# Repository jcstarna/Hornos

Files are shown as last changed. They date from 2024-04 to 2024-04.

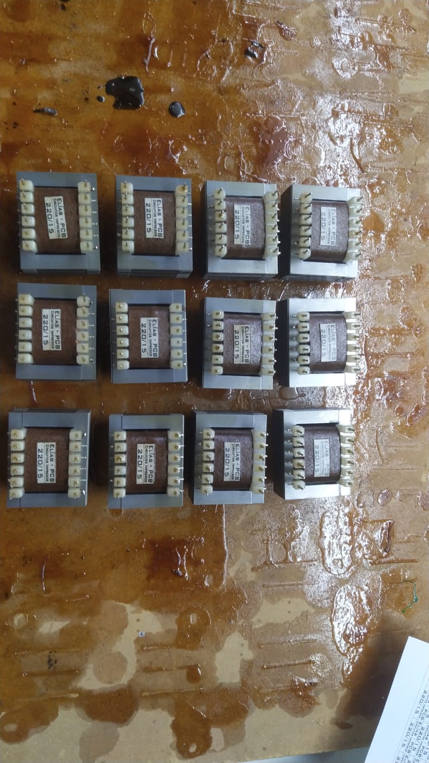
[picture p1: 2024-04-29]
docs/fotos/WhatsApp Image 2022-01-06 at 21.31.58.jpeg

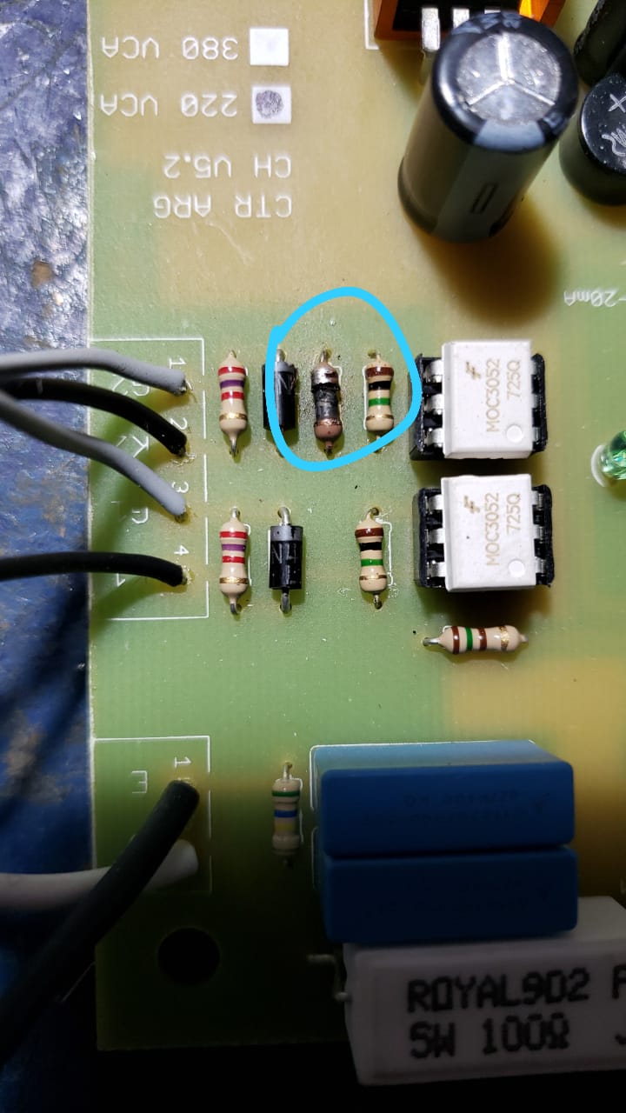
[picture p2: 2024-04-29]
docs/fotos/IMG-20210729-WA0018.jpg

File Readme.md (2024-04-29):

# Controlador de Hornos

Controlador de Hornos

## Requisitos
+ Puglin MPLAB 'CCS C Compiler' instalado. (Tools -> Plugins) 
+ Compilador CCS version 5.093 instalado en el sistema

## Verificar
+ Verificar que las rutas sean correctas en:  Project  -> Properties -> Conf: [nombre] -> CCS C Compiler -> Compiler Options -> Include Directoies

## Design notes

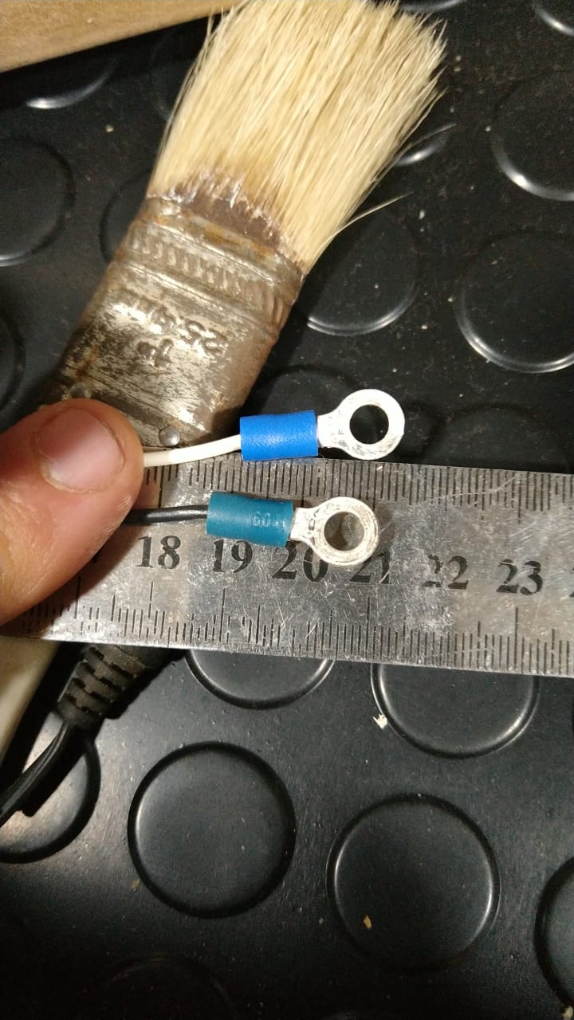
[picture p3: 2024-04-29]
docs/fotos/IMG-20210519-WA0052.jpg

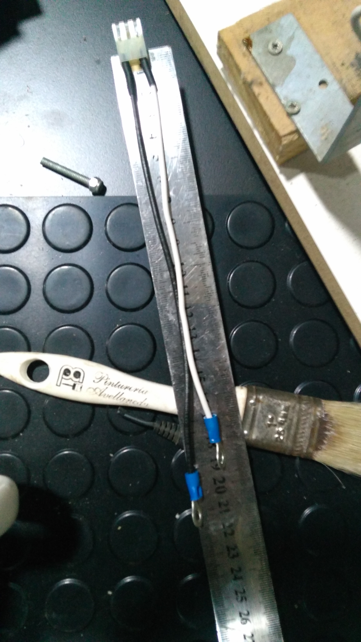
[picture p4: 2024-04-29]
docs/fotos/IMG-20210519-WA0053.jpeg

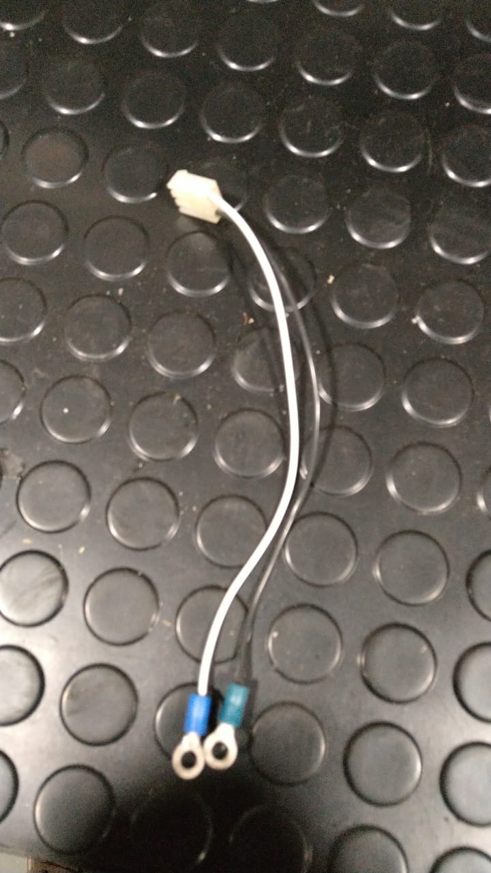
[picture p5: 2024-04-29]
docs/fotos/IMG-20210519-WA0051.jpg

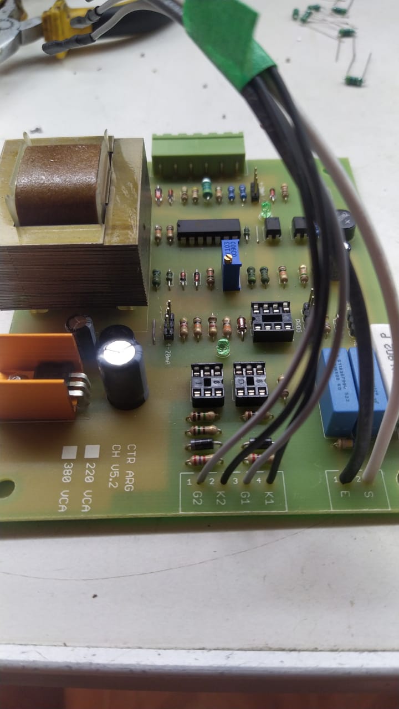
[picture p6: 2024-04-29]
docs/fotos/IMG-20210226-WA0002.jpg

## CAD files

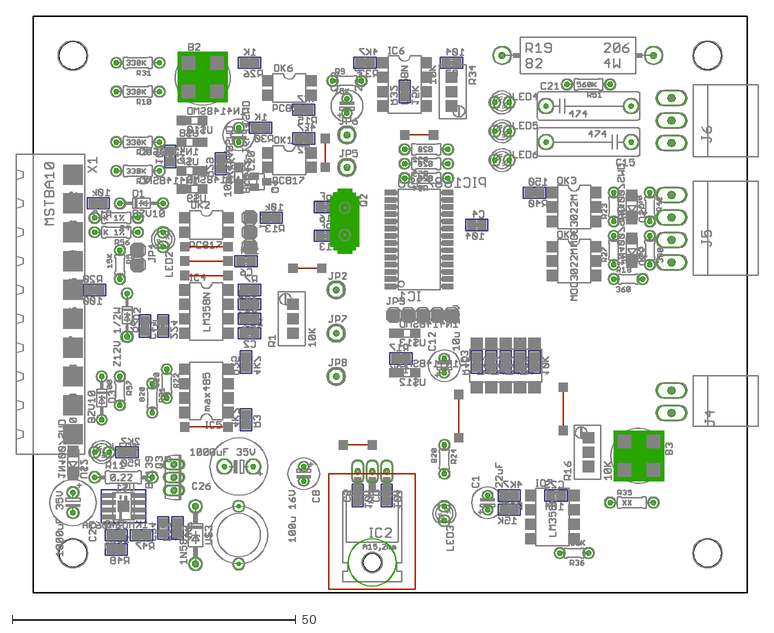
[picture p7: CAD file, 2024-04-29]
docs/ctrol_hornos_micro V32.dxf
130.7 x 101.6

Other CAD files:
docs/conexiones.dwg

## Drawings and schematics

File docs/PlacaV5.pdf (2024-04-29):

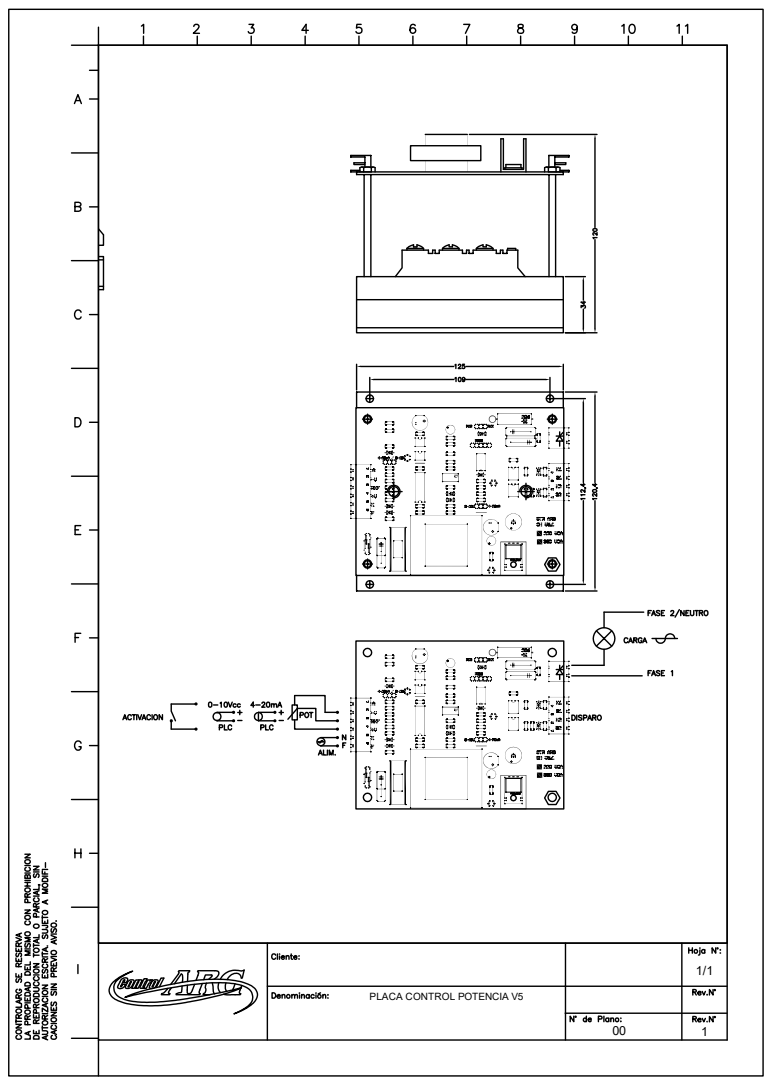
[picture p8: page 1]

PLACA CONTROL POTENCIA V5

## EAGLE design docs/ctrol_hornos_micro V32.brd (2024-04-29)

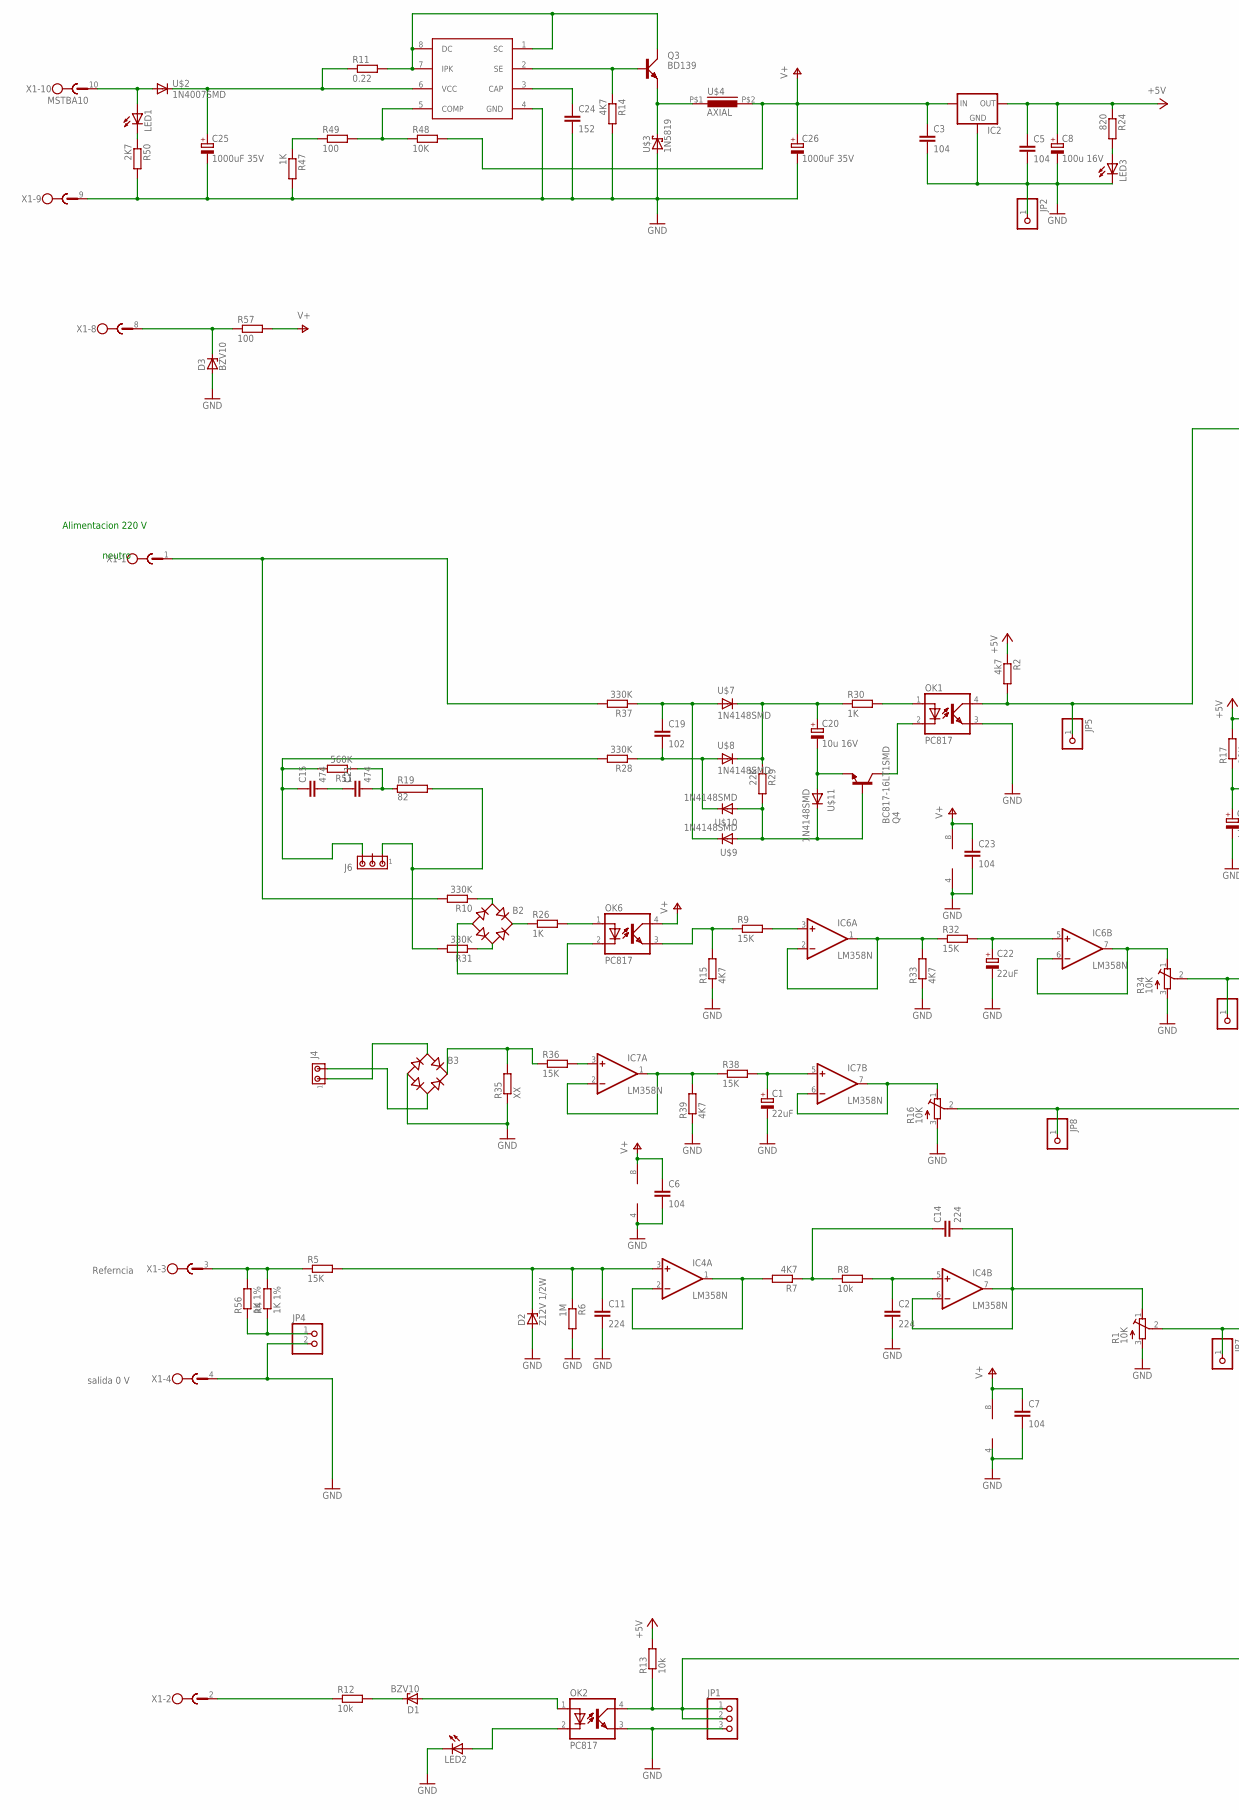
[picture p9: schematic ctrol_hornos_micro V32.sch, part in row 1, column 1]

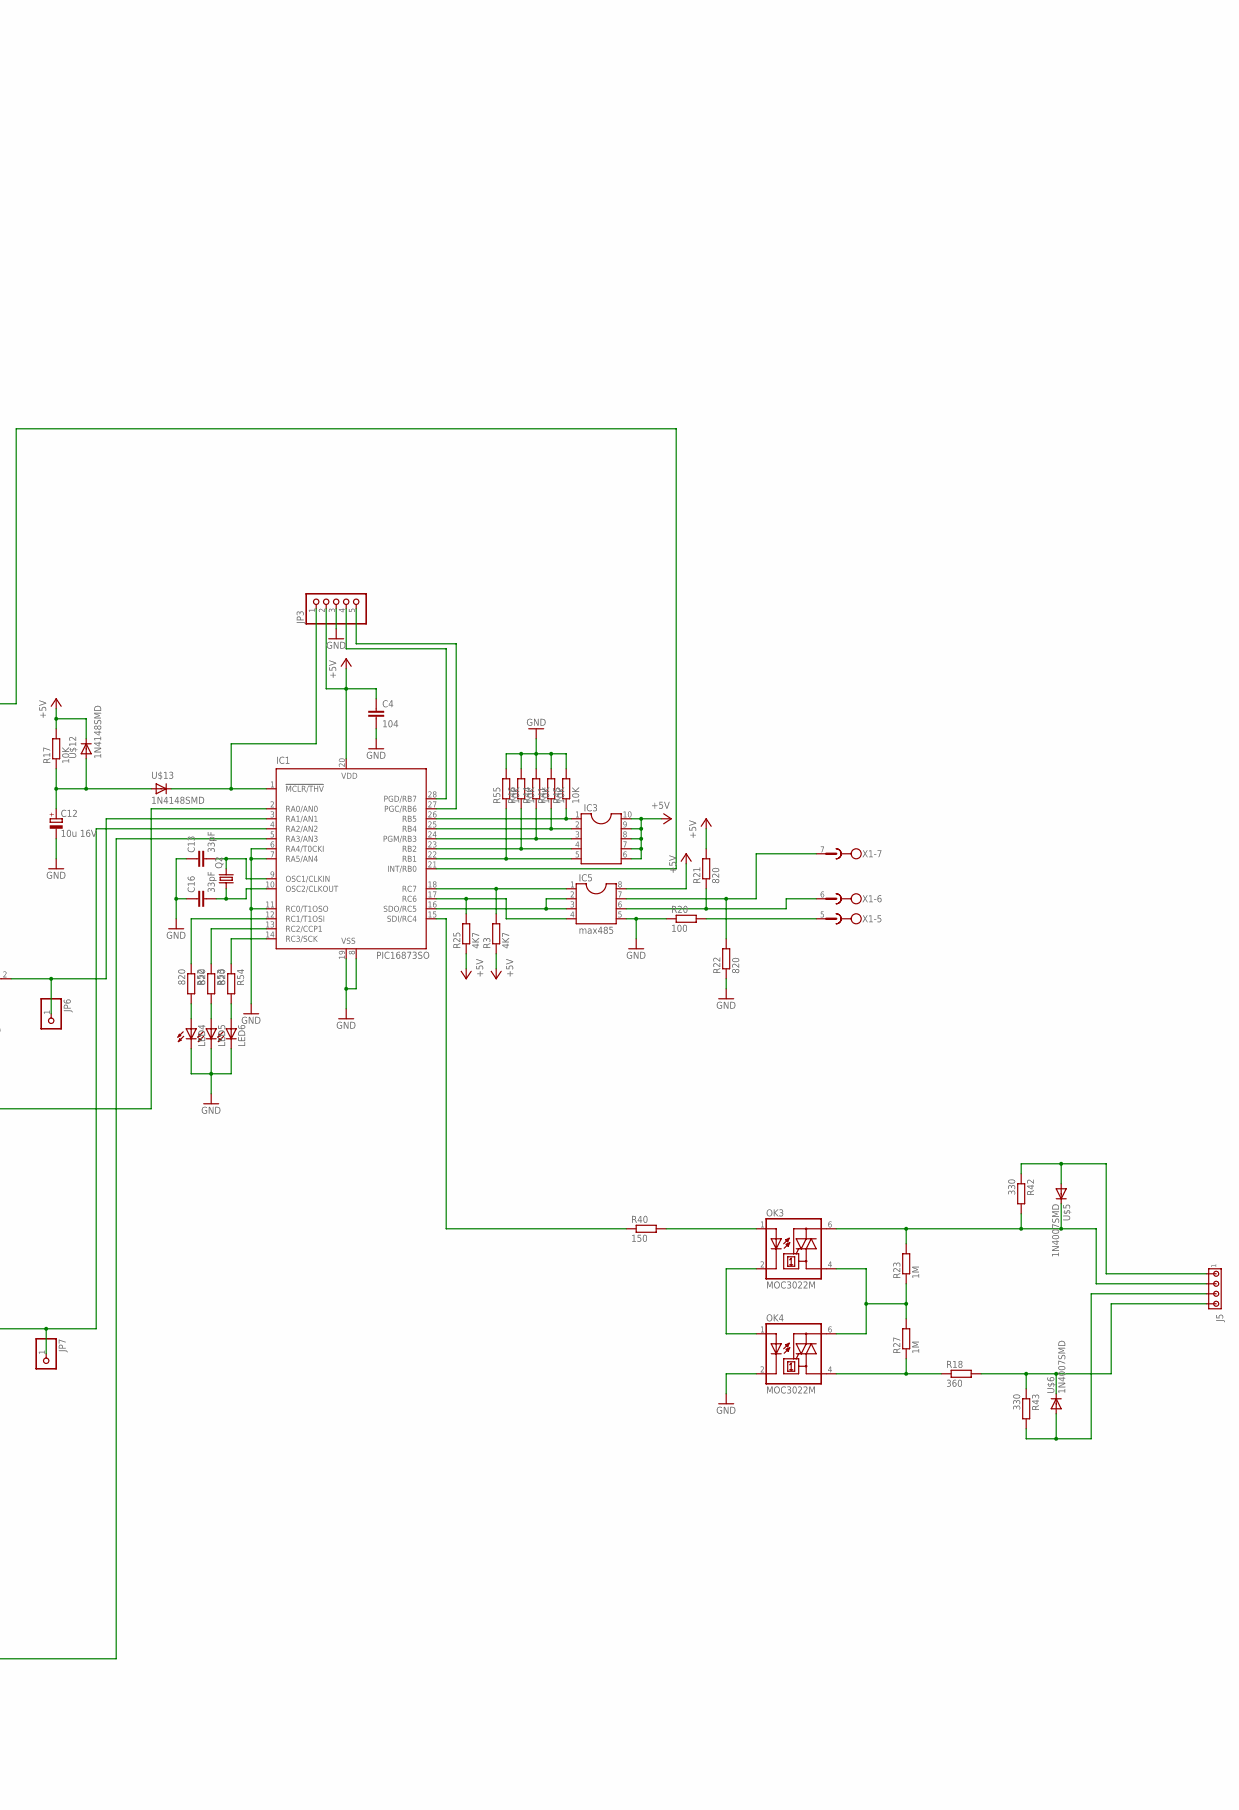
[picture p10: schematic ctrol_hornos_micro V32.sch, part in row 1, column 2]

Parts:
B2, B3: RB1A
C1, C22: 22uF; E2,5-6
C2, C11, C14: 224; C0805
C3, C4, C5, C6, C7, C23: 104; C0805
C8: 100u 16V; E2,5-6
C12, C20: 10u 16V; E2,5-6
C13, C16: 33pF; C0805
C15, C21: 474; C150-054X183
C19: 102; C0805
C24: 152; C0805
C25: 1000uF 35V; E3,5-8
C26: 1000uF 35V; E5-10,5
D1, D3: BZV10; DO34Z7
D2: Z12V 1/2W; DO34Z7
IC1: PIC16873SO; SO28W
IC2: 78XXL
IC3: DIL10
IC4, IC6, IC7: LM358N; DIL08
IC5: max485; DIL08
J4: MTA02-156; 1X2MTA
J5: MTA04-156; 1X4MTA
J6: MTA03-156; 1X3MTA
JP1: PINHD-1X3; 1X03
JP2, JP5, JP6, JP7, JP8: PINHD-1X1; 1X01
JP3: PINHD-1X5; 1X05
JP4: PINHD-1X2; 1X02
LED1, LED2, LED3, LED4, LED5, LED6: LED3MM
OK1, OK2, OK6: PC817; DIL04
OK3, OK4: MOC3022M; DIL06
Q2: CRYTALHC49S; HC49/S
Q3: BD139; TO126AV
Q4: BC817-16LT1SMD; SOT23-BEC
R1, R16, R34: 10K; RTRIMT93YA
R2: 4k7; M0805
R3, R7, R14, R15, R25, R33, R39: 4K7; M0805
R4, R56: 1K 1%; 0204/7
R5, R9, R36: 15K; 0204/5
R6: 1M; M0805
R8, R12, R13: 10k; M0805
R10, R28, R31, R37: 330K; 0204/7
R11: 0.22; 0207/10
R17, R41, R44, R45, R46, R48, R55: 10K; M0805
R18: 360; 0204/5
R19: 82; KH206-8
R20, R49: 100; M0805
R21, R22, R24: 820; 0204/5
R23, R27: 1M; 0204/5
R26, R30, R47: 1K; M0805
R29: 22K; M0805
R32, R38: 15K; M0805
R35: XX; 0204/7
R40: 150; M0805
R42, R43: 330; 0204/5
R50: 2K7; M0805
R51: 560K; 0204/7
R52, R53, R54: 820; 0204/7
R57: 100; 0204/5
U$1: MC34063A; SO-08
U$2, U$5, U$6: 1N4007SMD; DO214AC
U$3: 1N5819; DO41Z10
U$4: AXIAL; AXIAL1
U$7, U$8, U$9, U$10, U$11, U$12, U$13: 1N4148SMD; SOD123
X1: MSTBA10

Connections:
+5V: C4.1, C5.1, C8.+, IC1.20 (VDD), IC2.OUT, IC3.6, IC3.7, IC3.8, IC3.9, IC3.10, IC5.8, JP3.2, R2.1, R3.1, R13.2, R17.2, R21.2, R24.1, R25.1, U$12.C
GND: B3.-, C1.-, C2.2, C3.2, C4.2, C5.2, C6.2, C7.2, C8.-, C11.2, C12.-, C13.1, C16.1, C22.-, C23.2, C24.2, C25.-, C26.-, D2.A, D3.A, IC1.6 (RA4/T0CKI), IC1.7 (RA5/AN4), IC1.8 (VSS), IC1.11 (RC0/T1OSO), IC1.19 (VSS), IC2.GND, IC4.4 (V-), IC5.5, IC6.4 (V-), IC7.4 (V-), JP1.3, JP2.1, JP3.3, JP4.2, LED2.K (C), LED3.K (C), LED4.K (C), LED5.K (C), LED6.K (C), OK1.3 (EMIT), OK2.3 (EMIT), OK4.2 (C), R1.3 (E), R6.2, R14.2, R15.1, R16.3 (E), R20.1, R22.1, R33.1, R34.3 (E), R35.1, R39.1, R41.2, R44.2, R45.2, R46.2, R47.2, R50.2, R55.2, U$1.4 (GND), U$3.A, X1.4, X1.9
unnamed: LED1.A, U$2.A, X1.10
unnamed: R20.2, X1.5
unnamed: C12.+, R17.1, U$12.A, U$13.A
unnamed: C25.+, R11.1, U$1.6 (VCC), U$2.C
unnamed: IC1.26 (RB5), IC3.1, R45.1
unnamed: R10.2, R37.2, X1.1
unnamed: J6.1, R19.2, R31.2
unnamed: IC1.4 (RA2/AN2), JP7.1, R1.2 (S)
unnamed: Q3.C, R11.2, U$1.1 (SC), U$1.7 (IPK), U$1.8 (DC)
unnamed: B2.AC1, R10.1
unnamed: IC1.21 (INT/RB0), JP5.1, OK1.4 (COL), R2.2
unnamed: OK6.3 (EMIT), R9.1, R15.2
unnamed: B2.AC2, R31.1
unnamed: C20.+, R29.1, R30.1, U$7.C, U$8.C
unnamed: R4.2, R5.1, R56.2, X1.3
unnamed: C11.1, D2.C, IC4.3 (+IN), R5.2, R6.1
unnamed: IC4.1 (OUT), IC4.2 (-IN), R7.2
unnamed: C14.1, R7.1, R8.1
unnamed: C2.1, IC4.5 (+IN), R8.2
unnamed: IC6.3 (+IN), R9.2
unnamed: R12.1, X1.2
unnamed: IC1.3 (RA1/AN1), JP6.1, R34.2 (S)
unnamed: D1.C, R12.2
unnamed: C14.2, IC4.6 (-IN), IC4.7 (OUT), R1.1 (A)
unnamed: B2.+, R26.1
unnamed: LED2.A, OK2.2 (C)
unnamed: C24.1, U$1.3 (CAP)
unnamed: Q3.B, R14.1, U$1.2 (SE)
unnamed: IC1.28 (PGD/RB7), JP3.4
unnamed: OK1.1 (A), R30.2
unnamed: OK1.2 (C), Q4.C
unnamed: Q3.E, U$3.C, U$4.P$1 (1)
unnamed: IC1.5 (RA3/AN3), JP1.1, JP1.2, OK2.4 (COL), R13.1
unnamed: IC6.6 (-IN), IC6.7 (OUT), R34.1 (A)
unnamed: IC1.1 (!MCLR/THV), JP3.1, U$13.C
unnamed: C16.2, IC1.10 (OSC2/CLKOUT), Q2.1
unnamed: C13.2, IC1.9 (OSC1/CLKIN), Q2.2
unnamed: IC1.18 (RC7), IC5.1, R3.2
unnamed: C19.1, R37.1, U$7.A, U$9.C
unnamed: IC1.17 (RC6), IC5.4, R25.2
unnamed: C19.2, R28.1, U$8.A, U$10.C
unnamed: IC1.16 (SDO/RC5), IC5.2, IC5.3
unnamed: IC5.7, R22.2, X1.7
unnamed: IC5.6, R21.1, X1.6
unnamed: IC1.27 (PGC/RB6), JP3.5
unnamed: LED3.A, R24.2
unnamed: OK6.1 (A), R26.2
unnamed: B2.-, OK6.2 (C)
unnamed: IC1.12 (RC1/T1OSI), R52.1
unnamed: JP4.1, R4.1, R56.1
unnamed: IC1.15 (SDI/RC4), R40.1
unnamed: D3.C, R57.1, X1.8
unnamed: OK3.1 (A), R40.2
unnamed: OK3.2 (C), OK4.1 (A)
unnamed: OK3.4 (A1), OK4.6 (A2), R23.1, R27.2
unnamed: J5.2, OK3.6 (A2), R23.2, R42.2, U$5.C
unnamed: J5.4, R18.2, R43.1, U$6.C
unnamed: J5.3, R43.2, U$6.A
unnamed: J5.1, R42.1, U$5.A
unnamed: C15.2, C21.1
unnamed: C21.2, R19.1, R51.1
unnamed: IC1.13 (RC2/CCP1), R53.1
unnamed: C15.1, J6.3, R28.2, R51.2
unnamed: Q4.B, R29.2, U$9.A, U$10.A, U$11.C
unnamed: IC1.14 (RC3/SCK), R54.1
unnamed: C20.-, Q4.E, U$11.A
unnamed: LED4.A, R52.2
unnamed: LED5.A, R53.2
unnamed: LED6.A, R54.2
unnamed: IC1.22 (RB1), IC3.5, R55.1
unnamed: OK4.4 (A1), R18.1, R27.1
unnamed: C22.+, IC6.5 (+IN), R32.2
unnamed: IC6.1 (OUT), IC6.2 (-IN), R32.1, R33.2
unnamed: R48.1, R49.2, U$1.5 (COMP)
unnamed: D1.A, OK2.1 (A)
unnamed: B3.AC1, J4.1
unnamed: B3.AC2, J4.2
unnamed: IC1.25 (RB4), IC3.2, R41.1
unnamed: B3.+, R35.2, R36.1
unnamed: IC1.24 (PGM/RB3), IC3.3, R44.1
unnamed: IC7.3 (+IN), R36.2
unnamed: IC7.1 (OUT), IC7.2 (-IN), R38.1, R39.2
unnamed: C1.+, IC7.5 (+IN), R38.2
unnamed: IC7.6 (-IN), IC7.7 (OUT), R16.1 (A)
unnamed: IC1.2 (RA0/AN0), JP8.1, R16.2 (S)
unnamed: IC1.23 (RB2), IC3.4, R46.1
unnamed: R47.1, R49.1
unnamed: LED1.K (C), R50.1
V+: C3.1, C6.1, C7.1, C23.1, C26.+, IC2.IN, IC4.8 (V+), IC6.8 (V+), IC7.8 (V+), OK6.4 (COL), R48.2, R57.2, U$4.P$2 (2)

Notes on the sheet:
neutro
Alimentacion 220 V
Referncia
salida 0 V

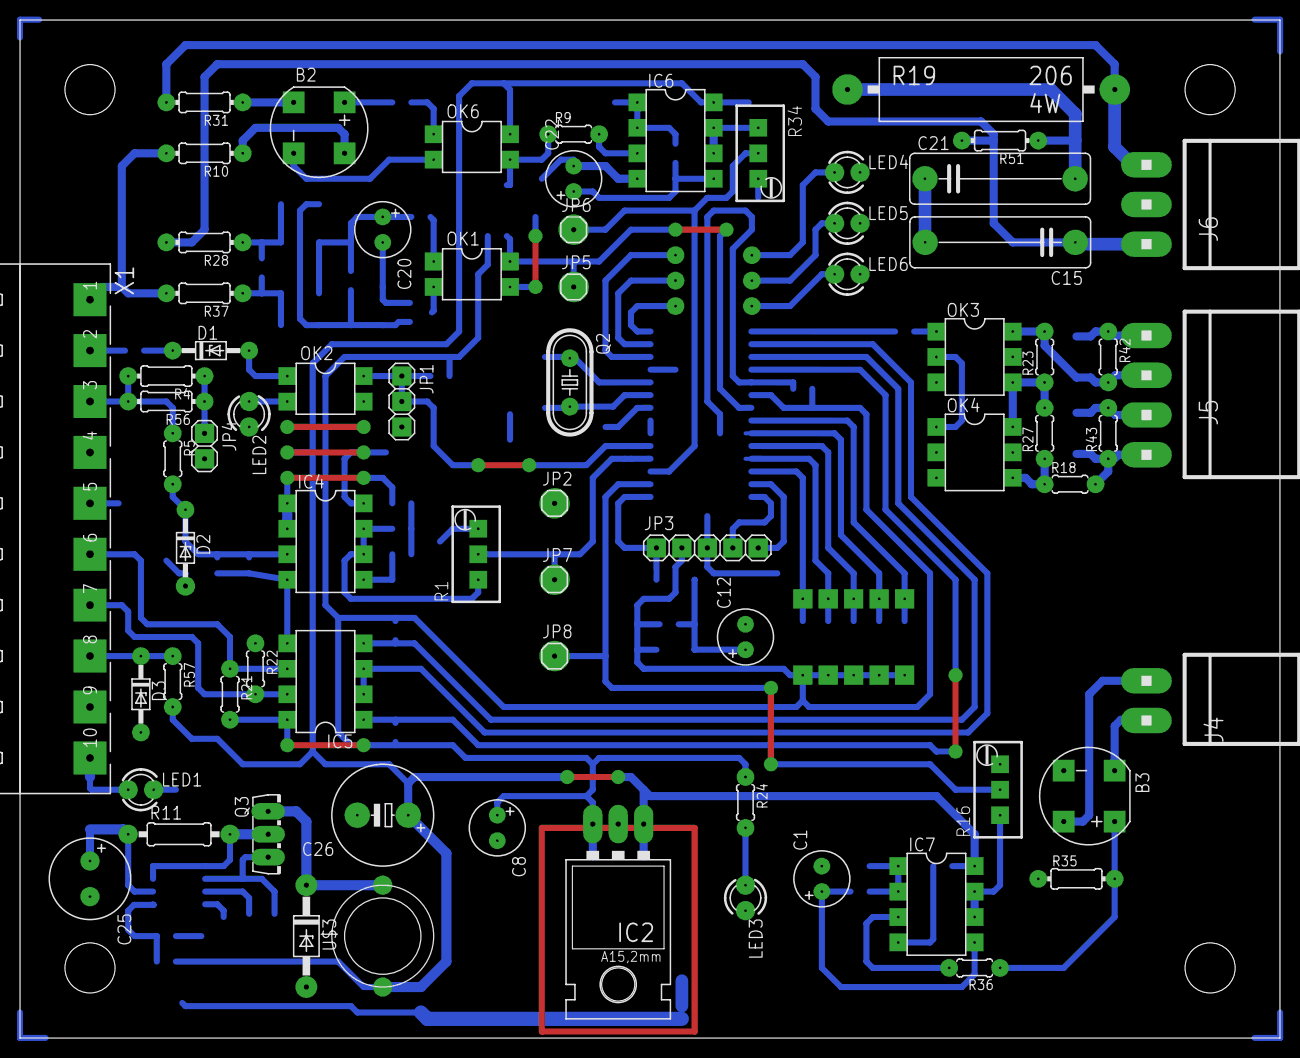
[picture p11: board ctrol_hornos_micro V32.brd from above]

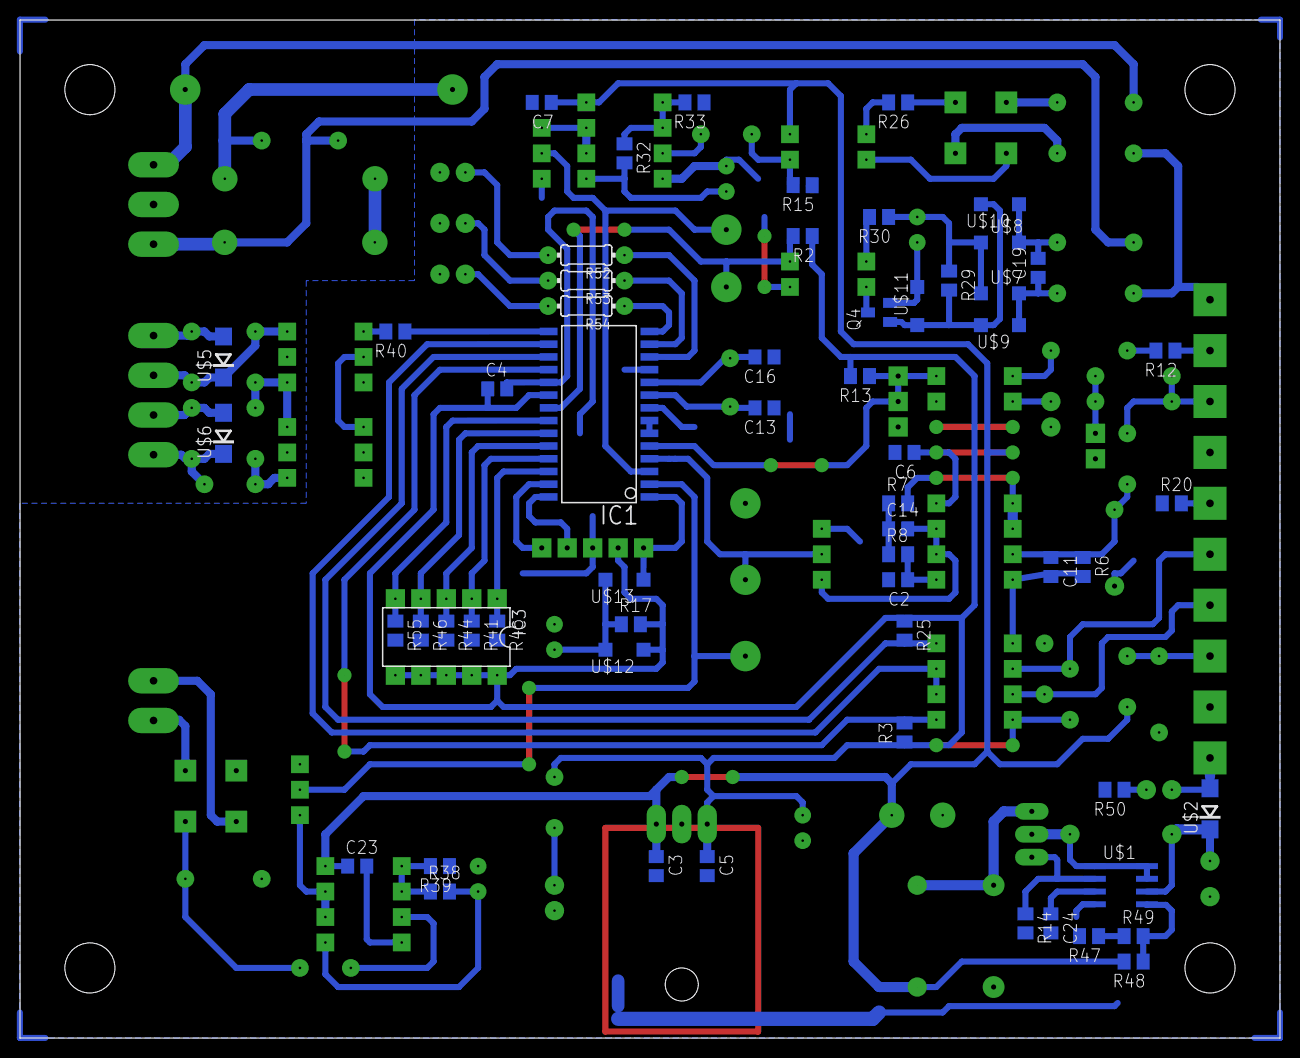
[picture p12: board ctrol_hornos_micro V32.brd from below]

Board: 2 copper layers, 125.7 x 101.6 mm, 130 parts (59 on the bottom side), 91 nets.

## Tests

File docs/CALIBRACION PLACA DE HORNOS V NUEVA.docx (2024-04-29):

CALIBRACION PLACA DE HORNOS V NUEVA

1. Colocar 10Vcc en entrada analógica.
2. Regular potenciómetro de entrada analógica para tener el valor 1000 en el registro 1 MODBUS.
3. Regular potenciómetro de realimentación para tener 380Vca en la carga.
4. Regular potenciómetro de entrada de corriente para obtener 75 Amp en el registro 3 de MODBUS

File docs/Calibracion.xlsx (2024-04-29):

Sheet: Hoja1
 |  |  |  |  |  |  | r teorica | 80.66666667 |  |  |  |  |  |  | 0.4031578947
 |  |  |  |  |  |  |  |  |  |  | pinza |  | AD |  |  |  |  |  |  |  |  |  |  |  |  |  | X | V
SP | PV | AD I | PINZA | Real (22vueltas) | TENSION |  | pot lamp | Cant Lamp | pot total | I esperada | P calc | R calc | pv X adi |  |  | I calculado | I sin 22 vueltas | Dif | % | PV/AD I | pv X adi | pot / Pot max | Raiz | %pot | SP |  | 4.46 | 347.295082
50 | 56 | 74 | 0.45 | 9.9 | 73 | 1.303571429 | 1000 | 4 | 4000 | 0.9049586777 | 32.85 | 162.2222222 | 4144 | 0.7567567568 |  | 5.419921875 | 0.2463600852 | -0.2036399148 | -45.25331439 | 0.7567567568 | 4144 | 0.005816140351 | 0.07626362403 | 76.26362403 | 50 | 26.26362403 |  | 0
100 | 95 | 109 | 0.62 | 13.64 | 102 | 1.073684211 |  |  |  |  | 63.24 | 164.516129 | 10355 | 0.871559633 |  | 7.983398438 | 0.3628817472 | -0.2571182528 | -41.47068594 | 0.871559633 | 10355 | 0.01453333333 | 0.1205542755 | 120.5542755 | 100 | 20.55427547 |  | 0
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

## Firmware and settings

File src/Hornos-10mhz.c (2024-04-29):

//control de lamparas por angulo de fase.
//Version 2 control de disparo por modulo CCP
//  03/07/08  agregado de arranque del modulo pwm para disparo de triac
//  08/07/08  implementacion de direccion para comunicacion

#include <16F873A.h>                          // Definiciones del PIC 16F873A
#DEVICE ADC=10
#fuses XT,NOWDT,NOPROTECT,NOLVP,PUT,BROWNOUT  // Los Fuses de siempre
#use delay(clock=10000000)                     // Oscilador a 4 Mhz
#use rs232(baud=9600, xmit=PIN_C6, rcv=PIN_C7, ERRORS)// RS232 Estándar

#pragma use fast_io(A)
#pragma use fast_io(B)
#pragma use fast_io(C)

#define pTiristor_On set_pwm1_duty(5)
#define pTiristor_Off set_pwm1_duty(0)


// CONSTANTES /////////////////////////////////////////////////////////////////
int const   lenbuff=23;
// VARIABLES EN RAM ///////////////////////////////////////////////////////////

INT  rDelay=10;            // Para lograr un tiempo determinado con la int del TMR0
int  rLeds=0;              // Imagen de los leds
int1 ctrlPot=0;            //define desde donde se controla la potencia 0=desde pote, 1=desde comunicacion
int1 fDisparo=1;           //esta disparando el triac

// Variables PID
int16 SP_Calc=0;        // Sp resultante de la comparacion del pv con el sp deseado(lectura Pote)
int16 SP=0;                // Tiempo en que se tiene que apagar V1
int16 PV=0;
signed int16 acuErr=10;
INT16 TEMP=0;
int1 fPID=0;

// Variables comunicacion
int1 fTX=0;          //Transmision pendiente
int  xbuff=0x00;     // Índice: siguiente char en cbuff
char Txbuff[lenbuff];// Buffer transmision
char Rxbuff[lenbuff];// Buffer recepcion
char rcvchar=0x00;   // último caracter recibido
int1 flagcommand=0;  // Flag para indicar comando disponible
int  txlen=0;        //longitud del buffer a transmitir
int  txpoint=0;      //Puntero del caracter a transmitir
int1 fEscOK=0;       //el mensaje recibido es para este esclavo
int  nEsclavo=0;     //Direccion de la placa


// Declaración de Funciones ///////////////////////////////////////////////////

void inicbuffTx(void);                 // Borra buffer
void inicbuffRx(void);                 // Borra buffer
int  addcbuff(char c);                 // añade caracter recibido al buffer
void echos(char c);                    // Eco selectivo sobre RS232
void procesa_comando(void);            // Procesa comando
void Control(void);                    //Calcula set point, error, determina SP_Calc.
INT16  PID(int16 SP,INT16 PV, KP, KI,signed int16 *aError);
                             // Lectura de la potencia actual en lampara


// INTERRUPCIONES /////////////////////////////////////////////////////////////

#int_rda
void serial_isr() {                    // Interrupción recepción serie USART
   rcvchar=0x00;                       // Inicializo caracter recibido
   if(kbhit()){                        // Si hay algo pendiente de recibir ...
      rcvchar=getc();                  // lo descargo y ...
      addcbuff(rcvchar);               // lo añado al buffer y ...
      //echos(rcvchar);                  // hago eco (si procede).
   }
}
//++++++++++++++++++++++++++++++++++++++
//  TRANSMISION SERIE.
//++++++++++++++++++++++++++++++++++++++
#INT_TBE
void serial_tx(){
   if(txlen!=0){
      putc(txbuff[txpoint]);
      txpoint++;
      txlen--;
   }
   else{
   disable_interrupts(int_tbe);
   inicbuffTX();
   txpoint=0;
   output_low(PIN_C3);
   }
}

#int_RTCC
void RTCC_isr() {                      // Interrupción Timer 0
   if(rDelay--==0){
      rDelay=9;
      fPID=1;}
}


///////// INTERRUPCION POR CRUCE POR CERO ////////////
#INT_EXT
void ext_isr(){
int16 rTemp1=0;
      disable_interrupts(int_ext);
      rTemp1=SP_Calc+1300;

     if(input(PIN_B0)){
         ext_int_edge(H_TO_L);
     }
     ELSE{
         ext_int_edge(L_TO_H);
     }
     set_timer1(0);
     CCP_2 = rTemp1;
     #ASM bcf  0xd,0
          bcf  0xc,2
     #ENDASM     
     enable_interrupts(int_ccp2);             // Habilito la interrpción INT_CCP2
     fDisparo=0;
    }    

///////// INTERRUPCION IGUALACION DE CCP_2 Y TIMER1 ////////////

#int_ccp2
void ccp2_int(){
int16 rTempT1;
   if (fDisparo){//ya esta disparando
      pTiristor_off;                //apago pwm
      enable_interrupts(int_ext);   //habilito interrupcion por cruce por cero
      fDisparo=0;
      disable_interrupts(int_ccp2);
   }
   else{ // tiene que empezar a disprara
      rTempT1=get_timer1();
      if (rTempT1<10500){
         pTiristor_on;                 //disparo
         CCP_2=rTempT1+100;            //SETEO TIEMPO DE DISPARO
         fDisparo=1;                   //marco que estoy disparando
      }
      else
         enable_interrupts(int_ext);   //habilito interrupcion por cruce por cero
   }
}

// Desarrollo de Funciones ////////////////////////////////////////////////////


void inicbuffRX(void){                   // Inicia a \0 cbuff -------------------
   int i;
   for(i=0;i<lenbuff;i++){             // Bucle que pone a 0 todos los
      Rxbuff[i]=0x00;                   // caracteres en el buffer
   }
   xbuff=0x00;                         // Inicializo el indice de siguiente
   }

void inicbuffTX(void){                   // Inicia a \0 cbuff -------------------
   int i;
   for(i=0;i<lenbuff;i++){             // Bucle que pone a 0 todos los
       txbuff[i]=0;
   }
   xbuff=0x00;                         // Inicializo el indice de siguiente
                                       // caracter
}

int addcbuff(char c){                  // Añade a cbuff -----------------------
      if (c == 0x0d)flagcommand=1;
      else Rxbuff[xbuff++]=c;
}


//,,,,,,,,,,,,Programa Principal /////////////////////////////////////////////////////////

void main() {

   delay_ms(500);
//++++++++++++++++++Configura puertos analogicos++++++++++++++++++++++++++++++
   setup_adc(  ADC_CLOCK_INTERNAL  );
   setup_adc_ports( ALL_ANALOG );                 // Ver que puertos van a ser analogicos
   setup_timer_0(RTCC_INTERNAL|RTCC_DIV_128);
   setup_timer_1(T1_INTERNAL|T1_DIV_BY_8);        
   setup_ccp2(CCP_COMPARE_INT);    // Configura CCP2 en modo COMPARE interrumpe cuando son iguales
   
   //Seteos puertos  
   set_tris_a (0b00000011);
   set_tris_b (0b00000001);
   output_c(0);
   set_tris_c (0b11010000);
   rDelay = 0;
   rLeds  = 1;

   ///PWM para disparo del tiristor
   set_pwm1_duty(0);
   setup_ccp1(CCP_PWM);
   setup_timer_2( T2_DIV_BY_1 , 20,2); 
   set_pwm1_duty(0);
            
   inicbuffRX();                                // Borra buffer al inicio
   inicbuffTX();                                // Borra buffer al inicio
   enable_interrupts(int_rda);                  // Habilita Interrupción RDA
   ext_int_edge(H_TO_L);
   enable_interrupts(int_RTCC);                 // Habilita Interrupción TIMER0
   enable_interrupts(int_ext);                  // Habilita Interrupción RB0, PASO DE BAJO A ALTO
   //enable_interrupts(global);                 // Habilita interrupciones
   set_timer1(0);
   output_b(0);
   output_c(0);
   fPID=1;
   
   do {
      if(flagcommand) procesa_comando();         // Si hay comando pendiente
                                             // de procesar... lo procesa.
      if(fPID){
            set_adc_channel(0);
            delay_us(100);
            if (!ctrlPot) SP=read_adc()/10;
            set_adc_channel(1);             
            delay_us(100);
            PV=read_adc()/10;
            fPID=0;
            //TEMP=PID (SP, PV,2,2,&acuErr);    
            SP_Calc=(SP/100)*10500;
            enable_interrupts(global);
            }
      
      if(fTX){
         fTX=0;
         output_high(PIN_C3);
         enable_interrupts(int_tbe); 
      }
      
   } while (TRUE);

}

// Procesador de Comandos /////////////////////////////////////////////////////

void procesa_comando(void){
   int32 SP_RX=0;
   int i=0;
   char a;                   // Argumento de comando (si lo tiene)

   flagcommand=0;                       // Desactivo flag de comando pendiente.


   if(Rxbuff[0]=='\\'&& Rxbuff[1]=='D'){   // Comparo inicio del buffer con comando "\@"
         //output_high(PIN_C3);
         sprintf(TxBuff,"%lu,%lu,%lu,%lu,%ld\r\n",SP,SP_Calc,PV,TEMP,acuErr);
         txlen=21;
         //enable_interrupts(int_tbe);
         fTX=1;
   }

   if(Rxbuff[0]=='\\' && Rxbuff[1]=='w'){   // Comparo inicio del buffer con comando "\w"
      a=Rxbuff[2];
      SP_RX=(int32)a;
      IF (SP_RX<=100) SP_RX= (1023*SP_RX)/100 , SP = (INT16)SP_RX;
         //output_high(PIN_C3);
         sprintf(TxBuff,"w:%lu,%3u",SP_RX,a);
         txlen=10;
         //enable_interrupts(int_tbe);
         fTX=1;
      }

   if(Rxbuff[0]=='\\' && Rxbuff[1]=='c'){   // Comparo inicio del buffer con comando "\w"
      i=Rxbuff[2];
      IF (i==0x31)
         ctrlPot=1;
      else if (i==0x30)
         ctrlPot=0;
         
         //output_high(PIN_C3);
         sprintf(TxBuff,"c:%2u",i);
         txlen=4;
         //enable_interrupts(int_tbe); 
         fTX=1;
      }
   inicbuffRx();                          // Borro buffer.
}




//++++++++++++++++++ RUTINA PID ++++++++++++++++++++++++++++++
//REFORMADA PARA QUE DE UNA SALIDA DE 0 A 100
//++++++++++++++++++++++++++++++++++++++++++++++++++++++++++++
INT16  PID(int16 SP, INT16 PV, KP, KI,signed int16 *aError)  {
signed int16 A=0;
signed int16 P=0;
signed int16 rI=0;
signed int16 Error=0;
int16   OUT=0;                     //Error actual
INT1  marca=0;

      Error=(signed int16)(SP-PV);

      if((-50 >= Error) && (Error >= 50)){
         Error=50;
      }

      P=Error*(signed int16)KP/10;         // Componente proporcional
      rI=(signed int16)KI;               // Componente integral
      rI=rI*Error*3/10;
      rI=rI+*aError;
      A=P+rI;
      if (A>100){                // Evaluo salida
         *aError=100-P;
         OUT=100;
         marca=1;
         }                       // Si es mas que el max, sale el max
      if (A<0){
         *aError=0-P;
         OUT=0;
         marca=1;
         }
      if (marca==0){
         *aError=rI;
         OUT=(INT16)(P+rI);
         }
         OUT=100-OUT;
      return OUT;
}

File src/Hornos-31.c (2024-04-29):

//control de lamparas por angulo de fase.
//Version 3 control de disparo por optoacoplador
//  03/07/08  agregado de arranque del modulo pwm para disparo de triac
//  Revision 2.1
//  08/07/08  implementacion de direccion para comunicacion
//  Revision 
//  07/10/08  Se saca interrupcion por comparacion y se precarga el timer1 y se apaga la
//             interrupcion cuando desborda el timer 1
//  Revision 
//  04/01/09  Implementacin de escritura del Set point de potencia desde PC
// 
//  Revision 
//  04/01/10  Modificacion del maximo tiempo de disparo para lograr apagado total
//             de la lamapara
//  Revison
//  07-11-12    Modificacion de micro a 16F883
//
//  Revision
//  19-06-13    Modificacion de disparo por optoacoplador
//             Agregado de TI para medicion de corriente
/*  Revision
    15/01/14   Agregado de comunicacion modbus
*/

#include <16f886.h>                          // Definiciones del PIC 16F873


#byte   OPTION_REG = 0x081
#bit    PS0 = OPTION_REG.0
#bit    PS1 = OPTION_REG.1
#bit    PS2 = OPTION_REG.2
#bit    PSA = OPTION_REG.3
#bit    T0SE = OPTION_REG.4
#bit    T0CS = OPTION_REG.5
#bit    INTEDG = OPTION_REG.6
#bit    RBPU = OPTION_REG.7

#byte   TXSTA_REG = 0x098
#bit    TRMT = TXSTA_REG.1

#DEVICE ADC=10
#fuses XT,NOWDT,NOPROTECT,NOLVP,NOBROWNOUT,MCLR,NODEBUG,PUT
#use delay(clock=4000000)                     // Oscilador a 4 Mhz
//#use rs232(baud=19200, xmit=PIN_C6, rcv=PIN_C7, enable=PIN_c3, ERRORS)// RS232 Estándar , enable=PIN_c3
#priority EXT,TIMER1,RTCC,RDA,TBE
#pragma use fast_io(A)
#pragma use fast_io(B)
#pragma use fast_io(C)

#use rs232(baud=57600, xmit=PIN_C6, rcv=PIN_C7, enable=PIN_c3, ERRORS)// RS232 Estándar , enable=PIN_c3

#define pTiristor_On output_high(pin_b1)
#define pTiristor_Off output_low(pin_b1)

// VARIABLES EN RAM ///////////////////////////////////////////////////////////

// Variables PID
//tabla para lectura desde PC//
int16 COM=0;               //Dir: 0 Comando desde PC
int16 EST=0;               //Dir: 1 Estado de la placa
int16 SP=0;                //Dir: 2 Set point de potencia
int16 PV=0;                //Dir: 3 Valor actual de potencia
int16 TI=0;                //Dir: 4 Medicion del TI
int16 Error=0;             //Dir: 5 Registro para cargar errores
int16 SP_Calc=1023;        //Dir: 6 Sp resultante de la comparacion del pv con el sp deseado(lectura Pote)
signed int16 acuErr=10;    //Dir: 7 Error en para el calculo de PID
INT16 TEMP=0;              //Dir: 8 Temporal
//fin tabla//
//tabla para escritura desde PC//
int16 REM_SP=0;            //Dir: 6 Set point remoto (desde PC)
#bit LR        = REM_SP.15

//DEFINICIONES DE LOS BITS DE ESTADO//
#bit fEstHab   =Est.0


//DEFINICIONES DE LOS BITS DE ERROR//
#bit fELamp    =Error.4
#bit fECom     =Error.3
#bit fETriac   =Error.2
#bit fESp      =Error.1
#bit fECero    =Error.0

//TIEMPOS EN LAS FALLAS
#define kT_falla_SP     100
#define kT_falla_Cero   50


INT  rDelay=10;            // Para lograr un tiempo determinado con la int del TMR0
int  rLeds=0;              // Imagen de los leds
int1 ctrlPot=0;            //define desde donde se controla la potencia 0=desde pote, 1=desde comunicacion
int1 fDisparo=1;           //esta disparando el triac
int1 fPID=0;
int1 fTX=0;
INT1 fHab=0;               //habilitacion de disparo.
int1 T2=0;                 //salto el T2
int  rTarea=1;             //Maquina de estados
INT16  rTDisp=0;

#include "ModBus.h"
#include "Modbus.c"

//Variables para deteccion de errores
int  rT_falla_SP  =    kT_falla_SP;      
int  rT_falla_Cero=    kT_falla_Cero; 

// Variables comunicacion
int1 fEscOK=0;       //el mensaje recibido es para este esclavo
int  nEsclavo=0;     //Direccion de la placa
int  rTinactiv=2;    //Tiempo para asegurar inactividad en la red
int  rCHKSUM=0;      //registro de checksum

// Declaración de Funciones ///////////////////////////////////////////////////
void Control(void);                    //Calcula set point, error, determina SP_Calc.
INT16  PID(int16 SP,INT16 PV, KP, KI,signed int16 *aError);
                            


// INTERRUPCIONES /////////////////////////////////////////////////////////////
//++++++++++++++++++++++++++++++++++++++
//  RECEPCION SERIE.
//++++++++++++++++++++++++++++++++++++++
#int_TIMER2
void TMR2_isr(){
int16 CRC=0;
int16 CRC_Leido=0;
t2=1;
/*
   IF(fParami){                        //Calculo checksum de dato recibido
         CRC=CRC_Calc(rxbuff,rxpuntero-3); //
         CRC_Leido= make16(rxBuff[rxpuntero-2],rxBuff[rxpuntero-1]);
         if(CRC_Leido==CRC)flagcommand=1;
         setup_timer_2(T2_DISABLED,0,1);
         rxpuntero=0;
         }
   else{
         inicbuffRX();
         rxpuntero=0;
         }
         setup_timer_2(T2_DISABLED,0,1);
*/
}

#int_rda
void serial_isr() {                    // Interrupción recepción serie USART
rcvchar=0x00;                        // Inicializo caracter recibido
   if(kbhit()){                           // Si hay algo pendiente de recibir ...
      rcvchar=getc();                     // lo descargo y ...
      ModBusRX(rcvchar);                // lo añado al buffer y ... 
   }  
   setup_timer_2(T2_DIV_BY_16,0xF0,5);
}

//++++++++++++++++++++++++++++++++++++++
//  TRANSMISION SERIE.
//++++++++++++++++++++++++++++++++++++++
#INT_TBE
void serial_tx(){
   ModBusTX ();
}

#int_RTCC
void RTCC_isr() {                // Interrupción Timer 0
   if(rDelay--==0){
      rDelay=3;
      if (rTarea++>3)rTarea=1;
      fPID=1;
      }
//Deteccion de errores
//falla falta de cruce por cero
   if(rT_falla_Cero--==0 & !fECero)fECero=1;
//falla no se puede alcanzar el sp
   if(rT_falla_SP--==0 & !fESp)fESp=1;
}


///////// INTERRUPCION POR CRUCE POR CERO ////////////

#INT_EXT
void ext_isr(){
int16 rTemp1=0;
     pTiristor_off;   //prueba 4/08/09
     output_toggle(pin_b4);
     rT_falla_Cero=    kT_falla_Cero;
     fECero=0;
     rTemp1=65535-(SP_Calc);
     if (rTemp1 > 64335)rTemp1=64335;     //maximo anterior (version 2.2 64035)
     if (rTemp1 < 57700)rTemp1=57700;     //minimo    65535-58535=

     set_timer1(rTemp1);
     #ASM bcf  0xd,0
          bcf  0xc,2
     #ENDASM  
     clear_interrupt(int_timer1);
     set_timer1(rTemp1);
     enable_interrupts(int_timer1);             // Habilito la interrpción INT_CCP2
     fDisparo=0;
  /*   if (fTX){ enable_interrupts(int_tbe);
               fTX=0;
    }   */ 
}
///////// INTERRUPCION IGUALACION DE CCP_2 Y TIMER1 ////////////
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

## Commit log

2024-04-29 primer commit
    [Calibracion.xlsx, conexiones.dwg, ctrol_hornos_micro V32.brd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]
2024-05-08 .gitignore dejo solo archivos escenciales para el proyecto
